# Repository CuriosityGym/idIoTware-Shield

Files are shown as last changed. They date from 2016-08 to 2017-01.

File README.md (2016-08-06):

# IdIoTware-Shield
##IoT with Arduino, Simplified

The idIoTware (pronounced “eye-dee-eye-oh-tee-ware”) Shield is a learning platform that offers both novices and advanced Arduino users, the opportunity to bring hundreds of projects alive quickly.

idIoTware provides an extremely flexible environment to express ideas and bring interactivity to simple projects, as well as providing for an easy way to implement, learn and prototype advanced projects and applications.

It is the “first of its kind” shield that offers this large variety of wireless communication options, input sensors, outputs and device extensibility. While offering high integration and compactness, the idIoTware Shield offers a large selection of latest hardware and features, accompanied by tested libraries, code and use cases. A must-have for the enthusiastic Arduino user.

##Product Images
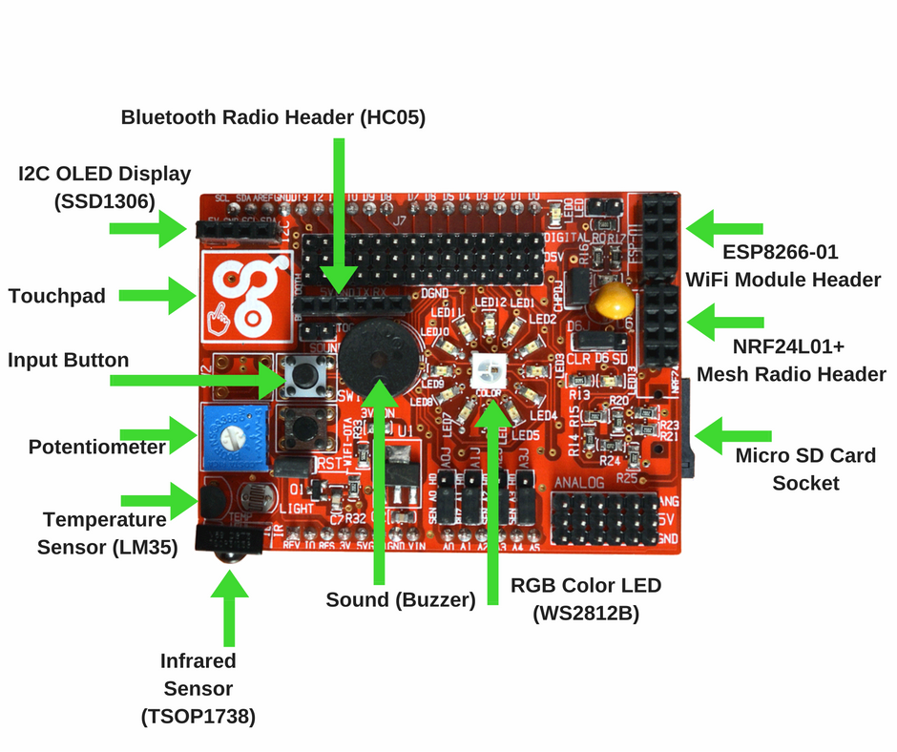
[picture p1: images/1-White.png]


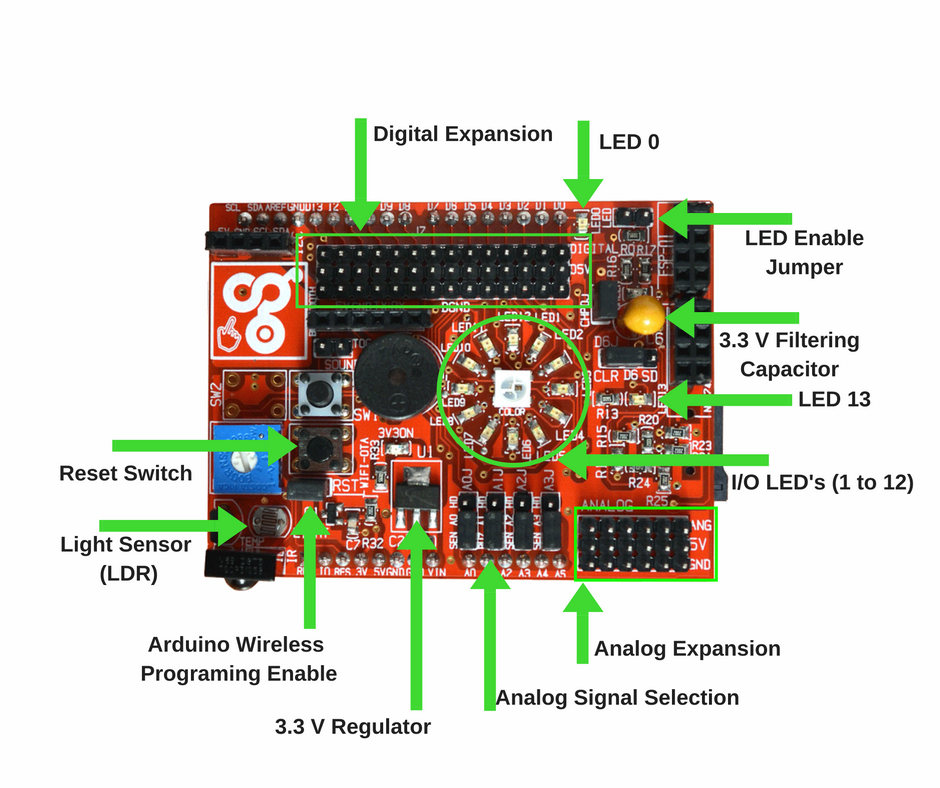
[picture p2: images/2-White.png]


##Hardware Specifications
#####Inputs

1. Integrated Temperature Sensor for measuring ambient temperature.
2. Integrated Light sensor that can measure relative light intensity.
3. Integrated Potentiometer to allow and simplify setting levels of intensity and thresholds.
4. Touch Pad and Input Switch to enable user inputs.
5. 38Khz Infrared Receiver which allows wireless remotes to control physical devices like robots.

#####Outputs

1. WS2812B Smart RGB LED for Colored Light Mixing.
2. I2C OLED Display for Visual Data Representation *
3. Multi tone Piezo buzzer for audio experiments.
4. Arduino Digital I/O’s connected to LED’s, enabling very quick debugging and error corrections.

#####Connectivity

1. ESP8226-01 Module to allow seamless Internet and Cloud Connectivity *
2. Connections and hardware that allows Arduino to be programmed over WiFi.
3. NRF24L01+ Module which allows for Mesh Networking and Collaborative Decision Making. *
4. Bluetooth and BLE Modules for connectivity to smartphones *

#####Extensibility/Advanced features

1. Expansion ports for Digital and Analog pins of Arduino.
2. Micro SD Card Socket for data accumulation and storage.*
3. Additional Voltage Regulator and onboard power conditioning hardware for 3.3 V devices.
4. Selection Hardware (Jumpers) for enable/disable features (User Selectable).
5. Compatible with Major Arduino Boards( new devices being added every week).

#####* Modules and SD Card to be purchased separately

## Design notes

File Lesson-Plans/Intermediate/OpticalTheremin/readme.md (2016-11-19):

#Optical Theremin
The theremin is a musical instrument that makes sounds as you wave your hand above it.

The light Dependent resistor or LDR is a light controlled variable resistor,
the resistance of a LDR decreases with increasing light intensity,
the resistance of LDR increases when the light intensity is decreasing,

However on the idIoTware shield, the LDR is wired such that with a higher Light intensity 
we get a higher Analog Voltage on Pin A3.

In this example we are going to use LDR sensor to make sounds.
When we wave our hand the light intensity falls on Light Dependent Resistor goes low .
This data is then captured by arduino through a voltage divider. 
We set the frequency according to the light value by using  map and tone functions in arduino to generate specific frequency .

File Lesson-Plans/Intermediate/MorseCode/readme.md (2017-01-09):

  **MORSE CODE**
    
    Morse code is a method of sending text messages by keying in a series of electronic pulses,
    usually represented as a short pulse (called a "dot") and a long pulse (a "dash"). The code 
    was devised by Samuel F. B. Morse in the 1840s
    
    In this example, we are using two NRF24L01 radio modules to transmit and receive Morse Code.
    On Transmitter side, Interpret presses on button (connected to digital pin 7) as Morse Code
    inputs and send it to receiver side using NRF24L01 radio.
    On Receiver side, NRF24L01 radio will receive the message and arduino will convert the signal 
    pattern consist of DOTs and DASHes to that particular letter and also print that letter to 
    OLED with its morse code.

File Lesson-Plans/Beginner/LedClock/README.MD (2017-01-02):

In this example 12 LEDs are used to show  time.  12 LEDs are connected in circualr pattern. All 12 LEDs represent number 1 to 12 of clock respectively. Depending upon the time, LED of that position will glow.If current time is 4:15 then 4th and 3rd LED will glow. 4th LED will indicate hour and 3rd LED will indicate minutes.LED which shows hours will glow conitinuously. LED which shows minutes will blink with delay of 1 sec. If time 6.30 then hour led and minute led will be the same (6th led) then 6th led will blink with delay of 250 miliseconds. e.g 4.20, 9.45, 11.55. We can set the current time in code.

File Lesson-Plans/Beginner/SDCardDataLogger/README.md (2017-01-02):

 SD card temperature logger
 This example shows how to log data from LM35 temperature sensor
 to an SD card using the SdFat library.
 In this example we have created a CSV file with the temperature values
 every one minute for 15 minutes. This interval rate and duration is configurable.
 If there is existing file, then it will create new file with different name.

 The circuit:
 LM35 sensor on analog pin A3
 
 SD card attached to SPI bus as follows:
 MOSI - pin 11
 MISO - pin 12
 CLK - pin 13
 CS - pin 4

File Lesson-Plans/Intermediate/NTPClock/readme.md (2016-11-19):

#NTP Clock

Most computers today use the NTP Clock to synchronise their internal clocks to an accurate atomic clock, 
which presents its time on the web.

#Working
In this example, we are going to display the Time, Date and Temperature readings on OLED display.
We need to setup the timezone first. 
By using idiotware.herokuapp.com, we are able to get the current zone  of the device, by using IP address. 
Once we get the timezone, we request timeapi.org to get the current time and date.
Once we get the data, we are ready to display it on OLED display.

Upload the code and you will be able to see the clock on the display with the current Time,date and temperature readings.

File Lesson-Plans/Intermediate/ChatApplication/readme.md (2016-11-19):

#Chat Application Using Idiotware Shield

What if, we could share data without wires or connecting to the Internet?

How cool would it be if you could communicate with people inside your home or work place
without a net pack or Internet Connection? 

A Private wireless Chat Room maybe?

What if we could customize our chat-screen with our own imaginations?

All this is possible with a arduino, idIoTware shield and the Wireless module nRF24L01. 

This Arduino Chat Room uses nRF24L01 to set up a low cost Chat Room in your local area.
You can extend the chat coverage by using nrf24l01 radio module with an external antenna.

#Working

In this example we are using NRF24L01 radio module and arduino to communicate to the other arduino and Nrf24L01 radio module using the serial monitor.

Here we are creating local mesh between two radio modules(Nrf24L01).

The two sets of  Arduino and nRF24L01 are connected together to establish a wireless  communication link so that they could talk to each other.

The nRF24L01 are half duplex transceiver modules, hence they can send and receive data.

The data is sent from the user using arduino Serial monitor , by typing on his keyboard,and this data can be received and displayed on the receivers  oled display,  which  is on the idiotware shield, and vice- a versa.

This project is limited to just adding two members to the Chat room, But the nRF24L01 has capability to handle 6 connections,  and so there could be a maximum of 6 members in our chat room, each talking or chatting with each other.

This chat room coverage could be upto 100 meters depending upon the nRF24L01 Modules range.

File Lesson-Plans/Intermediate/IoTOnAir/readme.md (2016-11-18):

**IOT OnAir**
-------------

This is a device that could be used to notify any specific content on google calendar with idIoTware Shield.

The event from the Google calendar notifies the Maker channel on the IFTTT server. 
Once the maker channel is triggered, it will then send a ‘Get request’ to the blynk server.

For example: http://blynk-cloud.com/yourAPIkey/update/V0?value=250?pin=V0&value=0&pin=V0&value=0

Note: here "value" is the whole number that is used to set intensity of red color on idIoTware shield from 0 to 255.

So what is IFTTT?
-----------------

IFTTT is a free web-based service that allows users to create chains of simple conditional statements, called "recipes", which are triggered based on changes to other web services such as Gmail, Facebook, Instagram, Twitter and many more.

IFTTT is an abbreviation of "If This Then That".

User can use the maker channel to connect there hardware with other services and trigger them according to the recipes.

For example: The event from the google calendar notifies the maker channel on the IFTTT server.
Once the maker channel is triggered, it will then send a ‘Get request’ to the blynk server.

Configuring IFTTT and Blynk APP
-------------------------------

1. Go to www.ifttt.com

2. Sign in the account

3. Create new applet

4. Select Google Calendar.

5. For this example we choose event from search starts. NOTE:You can choose any of the three.

6. Write the keyword you want to trigger from Google Calendar.

7. Add Maker channel

8. Select Make a web request

9. You will need to add url for blynk server and change content type to text/plain
10. Create new project and email the token key

In your Arduino program, you need to copy the Token key generated in the blynk app and also need to write your ssid and password for wifi . You are now ready to upload the code. You will see your ON Air light up when the google calendar event is called.

1. Configuring Arduino IDE and idIoTware shield

2. Connect One jumper to CHPD for enabling esp8266

3. Connect One jumper to CLR means color that is RGB LED and D6.

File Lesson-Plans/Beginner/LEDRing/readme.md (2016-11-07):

#idIoTware Shield LED Ring Demo

This Arduino program demonstrates the ring of LED's on the shield to light up one after the other.

###Hackster Project
https://www.hackster.io/30115/led-ring-patterns-7f5cd2?ref=channel&ref_id=29476_trending___&offset=1

###Video

https://www.youtube.com/watch?v=BFscHxyjzhA

#Hardware Required
1. idIoTware Shield
2. Arduino Uno.
3. USB cable to connect arduino  to computer
4. One jumper to enable the LED Ring

The following patterns defined in the sketch.

a. Sweep

b. Half Circle

c. A Curtain

d. Fast and Slow Pattern.

The LED’s on the ring are connected from Digital Pin 1 to Digital pin 12 of the Arduino.

We need to initialize this LED's in void setup() function of arduino sketch, to be outputs.

The void loop() runs over and over again, repeatedly till power is removed. Out LED patterns are executed within the loop().

We will use the function for example the sweep(1).The “1” means how many repetitions you wish to do for that animation.This value can only be whole numbers, and not with decimal points. 

In a similar manner, you can also use the other functions to mix and match animations on the LED Ring.

Additionally,you can use touch pad or potentiometer as the input to control the 12 led’s.

You can now make your own program and create patterns on the LED’s and put this up on your Christmas tree
or any other decorations to bring that interactive look to your project.

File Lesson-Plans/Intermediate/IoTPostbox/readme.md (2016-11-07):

#IoT PostBox
    
In this project, I am going to demonstrate how to build your own IoT aware Postbox with the help of the idIoTware shield in a few easy steps. This postbox alerts you about new envelopes dropped inside a postbox by the mailman. 

### Hackster Project
https://www.hackster.io/30290/smart-iot-postbox-3287f8?ref=user&ref_id=11008&offset=1

### Video 

https://www.youtube.com/watch?v=VOWjkQzXQHM

You will need the following things to get started. 
An Arduino UNO
idIoTware shield. 
USB cable to connect arduino  to computer.
Esp 8266 - 01, programmed with ESP-link firmware
One jumper to enable the Chpd pin.
One Postbox
External 9v 1A Power adapter.   

The LDR ( Light Dependent Resistor)  on IdIoTWare shield is used as sensor to detect a letter being dropped into the letterbox. The on board WS2812 Led (addressable RGB LED) on IdIoTWare shield is continuously ON (WHITE Color) which acts as a light source, and reflects light onto the LDR. As soon as a letter is dropped into the postbox, there is an interruption in light -  the light intensity on LDR changes due to reflection. The Arduino continuously monitors the change in the value of the LDR and when it notices a change in value, it sends an email.  Here we are using IFTTT to send a pre configured email. 

###So what is IFTTT?
Introduction Video to IFTTT https://www.youtube.com/watch?v=CEAVFU3ELcI

IFTTT is an abbreviation of "If This Then That"

IFTTT is a free web-based service that allows users to create chains of simple conditional statements, called "recipes", which are triggered based on changes to other web services such as Gmail, Facebook, Instagram, and many more.

You need to  create an account on IFTTT and create your recipe.

You need to make the IFTTT account. click on the link below https://ifttt.com/join and sign up the account.

We are using Maker and Gmail channel to trigger an event.
If there is new letter in postbox, Arduino will send POST request to Maker channel.
if Maker then Gmail’
If Maker Event "New Letter",
then send an email from "abcd@gmail.com".

Connect the esp8266 01 module to ESP-01 header on the top right, such that the antenna is facing outside. ( See Image) We need to Connect jumper to the chpd pin header for the esp to work correctly. 

Once we upload the code in arduino, place the Arduino with double sided sticky tape inside the postbox. Make sure the whole bottom of the arduino board is insulated from the metal areas of the postbox. Post the letter in the box, and you will see the message” new Letter!! “ in serial monitor and when you check your mail you will find IFTTT message saying you got a letter!!

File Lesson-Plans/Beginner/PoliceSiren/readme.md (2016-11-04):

# Police Siren with the idIoTware Shield

### Hackster project
https://www.hackster.io/30210/police-siren-bf8169?ref=channel&ref_id=29476_trending___&offset=0

### Video
https://youtu.be/00wCUanNaoU

### Project Description

In this project, I am going to demonstrate how to make your own police siren alarm with the help of the idIoTware shield.

You will need following things to get started. 
An Arduino Uno.
An idIoTware shield. 
A USB cable to connect Arduino to Computer.
A 2 pin Jumper to connect the Buzzer to the Arduino A1 pin.
A jumper that connects CLR to D6 for Color LED.

The buzzer is already connected on the shield, but it has to be enabled using the 3 pin  Selection Jumper SEL 1.

We need to Connect the “BUZ” pin to the center pin on SEL1 3 pin header, effectively connecting the Buzzer to the A1 pin.

In method police_siren() the tone for the siren is mentioned.Use this function in the loop to run the siren over and over again.

For more reference on tone function please visit the link in the description.  

Once we upload the code in arduino, we are going to hear the police siren, along with the RGB Color LED showing a Red and Blue blinking light.

You can now make your own program that play siren when someone unauthorized comes at your house.This will alert the neighbours about activity inside your home.  

You can also use the buzzer to alert you when the temperature increases beyond a certain limit, as measured by the integrated temperature sensor on the idIoTware shield. We will learn how to measure temperature in a later video. 

Another use for the buzzer is to generate any set of tones like nursery rhymes or the happy birthday song.

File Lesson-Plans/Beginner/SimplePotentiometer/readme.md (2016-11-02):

  A potentiometer, or "pot" for short, is a control knob.
  It's the same type of control you'd use to change volume,
  dim a lamp, etc. A potentiometer changes resistance as it
  is turned. By using it as a "voltage divider", the Arduino
  can sense the position of the knob, and use that value to
  control whatever you wish.

  In this example we are going to Turn ON and OFF sequence of 12 LEDs
  depending upon the position of the knob of potentiometer.
  As we turn potentiometer from initial position to final position,
  12 LEDs will glow one by one depending to value of potentiometer.
  If we turn knob in reverse direction then LEDs will turn OFF one by
  one depending upon the value of potentiometer

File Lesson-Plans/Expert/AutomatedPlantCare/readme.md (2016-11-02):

#**idIoTWare Shield Hydroponics**
#####**Attention: Please install all libraries from our Github Repository to enable this example to run.**

In this example we are using ESP8266-01 Wifi Module with esp-link firmware, Soil moisture sensor to sense moisture in soil, walter level sensor to detect water level and motor to water the plant. If plant's soil is dry then moisture sensor will give HIGH input to arduino then arduino turns ON the motor. We have used mosfet to turn ON and turn OFF the motor. Arduino logs the data on thingspeak and sends mail to the user.                                                    

ThingSpeak is an open source Internet of Things (IoT) application and API to store and retrieve data from things using the HTTP protocol over the Internet or via a Local Area Network. ThingSpeak enables the creation of sensor logging applications, location tracking applications, and a social network of things with status updates. To log the data to thingspeak, you need to create thingspeak account and then create channel and use that channel's API Key in this code.                

Here we are using IFTTT to trigger an event.                                                                             
IFTTT is a free web-based service that allows users to create chains of simple conditional statements,
called "recipes", which are triggered based on changes to other web services such as Gmail, Facebook,
Instagram, and many more.IFTTT is an abbreviation of "If This Then That"
Create account on IFTTT and create your recipe.

We are using Maker and Gmail channel to trigger an event.

If plant is watered, Arduino will send POST request to maker channel.  
if Maker then Gmail
If Maker Event "Plant_watered", then send an email from "abcd@gmail.com"  

#####**Setup:**
1.create account on thingspeak and channel                                         
2.create account on IFTTT, connect to maker channel and make recipe.                                                    
3.replace API key for thingspek channel and maker channel                                                     
4.install all libraries from our Github Repository to enable this example to run.                                         
5.connect sensors to proper input pins and caliberate the sensors for perfect reading.

#####**Precautions:**
1.Use mosfet or relay module to drive motor.                                                                             
2.keep sensor properly in soil to get proper readings

#####**Images:**  put link here

#####**Video:**  put link here

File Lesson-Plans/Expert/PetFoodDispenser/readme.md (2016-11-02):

# **idIoTWare Shield Dog Food Feeder**
#####  **Attention: Please install all libraries from our Github Repository to enable this example to run.**
    
In this example we are using ESP8266-01 Wifi Module  and a Servo motor to dispense food from 3d printed food jar.

Blynk is a platform with iOS and Android apps to control Arduino, Raspberry Pi and the likes over the Internet. 
You can easily build graphic interfaces for all your projects by simply dragging and dropping widgets.

Downloads, docs, tutorials: http://www.blynk.cc
  Blynk community:            http://community.blynk.cc 

To send data from Blynk to arduino or get data from arduino to blynk app you need to install Blynk app on your 
smartphone, create account to log in to the app then you will get a unique token number then use that token number in 
this code to create your own project.

In this example we have used ESP8266_Lib.h and BlynkSimpleShieldEsp8266.h  library to make communication between arduino
and Blynk app.We have used Servo.h library to control servo motor. In this code we have used vitual pin(v1) to receive data 
from blynk app. oN Blynk app we have added a button icon to send ON and OFF signal to arduino. If you press button then servo
will rotate 60 degree in clockwise direction and food will get dispensed for 5 seconds and after thet servo will come back to 
initial positon. You can change rotation angle of servo and time for which you want to dispense food. 

#####**Setup:**

1.install all libraries from our Github Repository to enable this example to run.                                 
2.create account on BLYNK and use your Auth Token number in code.                               

#####**Precautions:**

1.Enter correct Auth Token number.                                                                                 
2.Virtual pin number in code and BLYNK app must be same.                                                                 

#####**Images:** put link here
#####**Video:** put link here

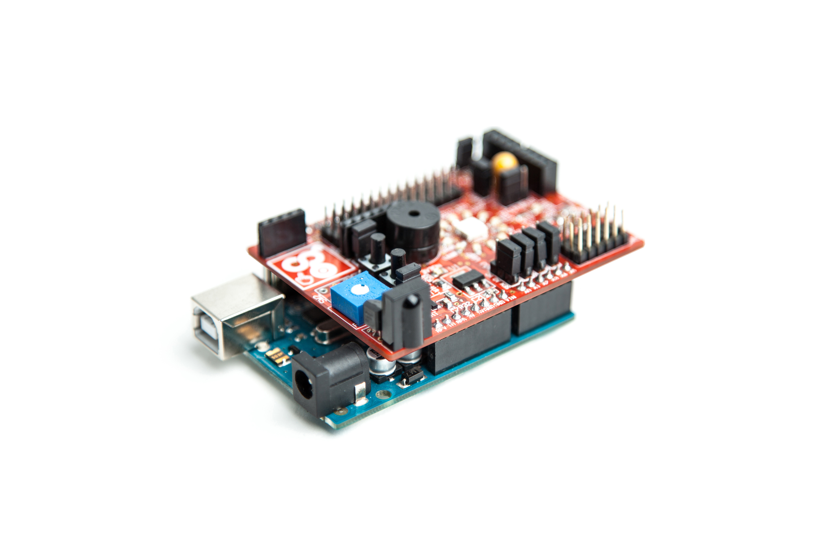
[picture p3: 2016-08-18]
images/idIoTware Shield On Arduino Perspective.jpg

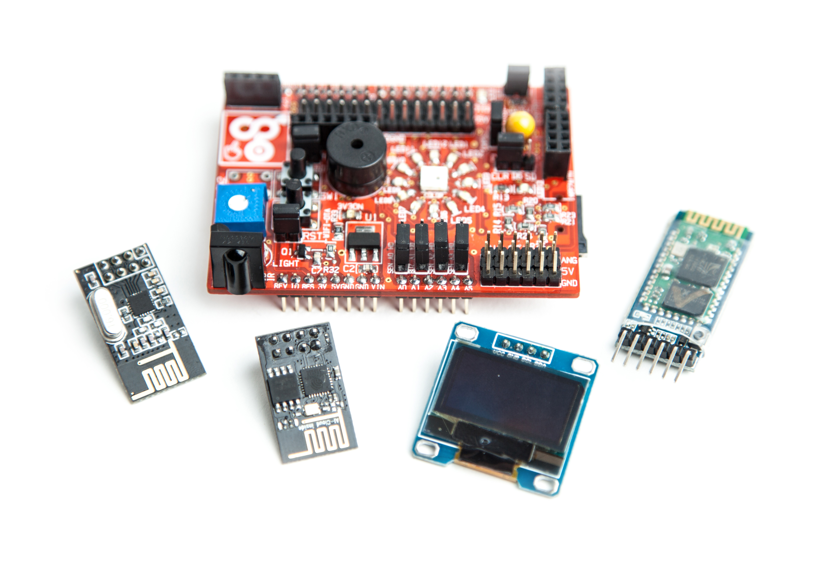
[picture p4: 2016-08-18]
images/idIoTware Shield with Modules.JPG

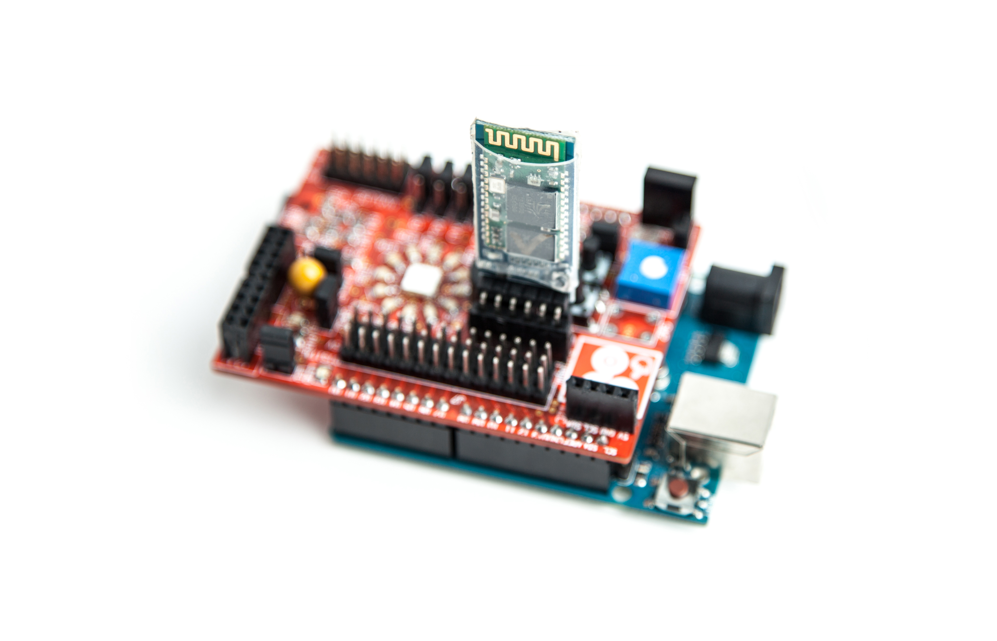
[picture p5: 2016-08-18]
images/idIoTware Shield On Arduino with Bluetooth.JPG

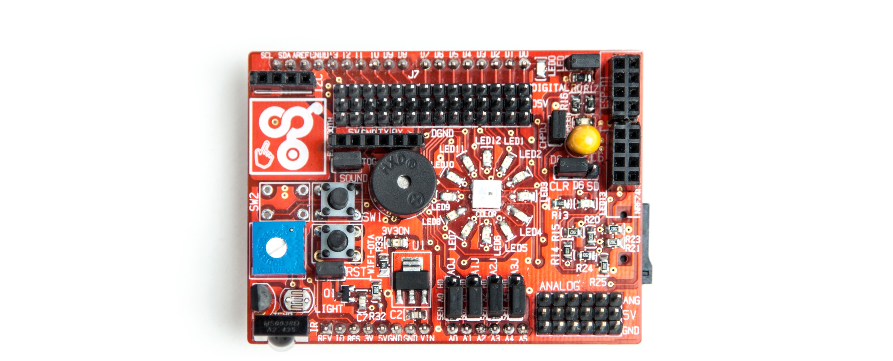
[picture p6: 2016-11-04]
images/idIoTware Shield Top View.JPG

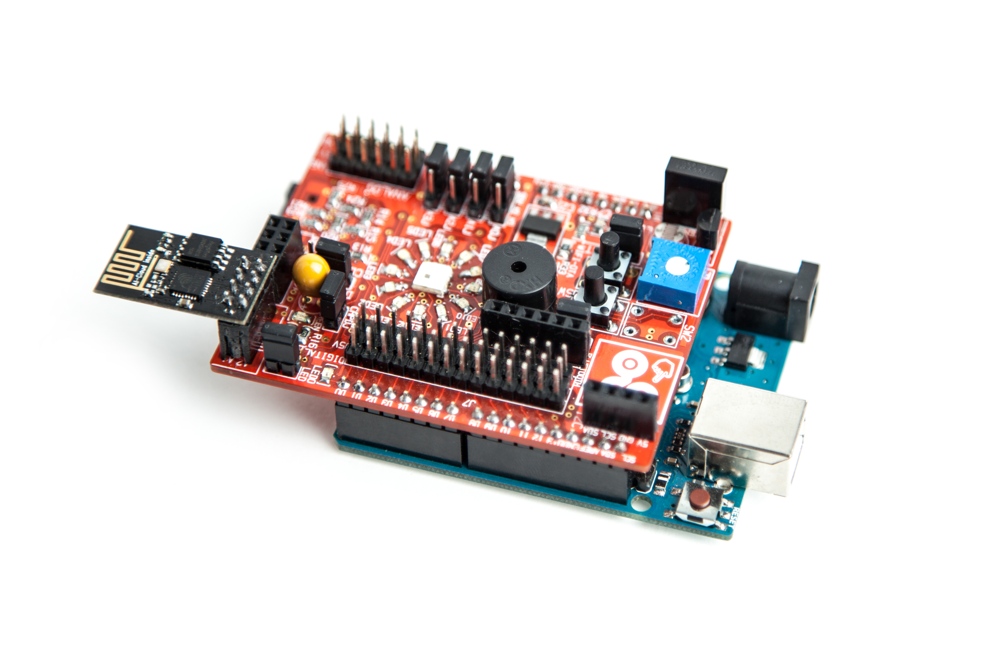
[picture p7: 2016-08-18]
images/idIoTware Shield On Arduino with ESP-01.JPG

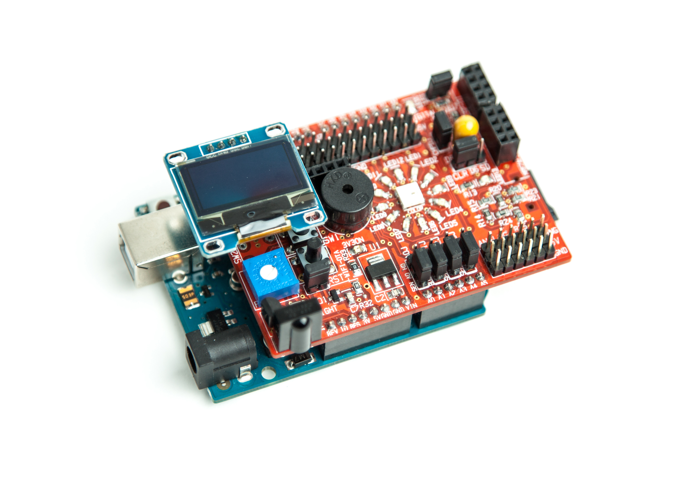
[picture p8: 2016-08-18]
images/idIoTware Shield On Arduino with OLED.JPG

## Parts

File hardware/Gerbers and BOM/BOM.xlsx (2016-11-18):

Part | Value | Device | Package | Description
PCB |  | PCB | 74mm by 56 mm | PCB Material :(Rigid)FR－4 PCB Size: (74 mm ) × (56 mm ) PCB Layer: 2 Thickness: 1.6mm Copper Weight: 1oz PCB Colour: Red Silkscreen:White Pads Finished: HASL lead free Via solder mask :solder mask cover Minimum trace/space: 8mil Minimum hole size: 13 mil
0 |  | LEDCHIPLED_0805 | CHIPLED_0805 | RED LED
1 |  | LEDCHIPLED_0805 | CHIPLED_0805 | RED LED
2 |  | LEDCHIPLED_0805 | CHIPLED_0805 | RED LED
3 |  | LEDCHIPLED_0805 | CHIPLED_0805 | RED LED
3.3V_REG |  | V_REG_LM1117SOT223 | SOT223 | Voltage Regulator LM1117 VREG-08170 RegulatorLM1117VREG-08170
3.3V ON |  | M02PTH | 1X02 | Standard2-pin0.1"header.
4 |  | LEDCHIPLED_0805 | CHIPLED_0805 | RED LED
5 |  | LEDCHIPLED_0805 | CHIPLED_0805 | RED LED
5V |  | M06SILK_FEMALE_PTH | 1X06 | Header6CONN-08437
6 |  | LEDCHIPLED_0805 | CHIPLED_0805 | RED LED
7 |  | LEDCHIPLED_0805 | CHIPLED_0805 | RED LED
8 |  | LEDCHIPLED_0805 | CHIPLED_0805 | RED LED
9 |  | LEDCHIPLED_0805 | CHIPLED_0805 | RED LED
10 |  | LEDCHIPLED_0805 | CHIPLED_0805 | RED LED
11 |  | LEDCHIPLED_0805 | CHIPLED_0805 | RED LED
12 |  | LEDCHIPLED_0805 | CHIPLED_0805 | RED LED
13 |  | LEDCHIPLED_0805 | CHIPLED_0805 | RED LED
SEL0 |  | JP2E | JP2 | JUMPER
SEL1 |  | JP2E | JP2 | JUMPER
SEL2 |  | JP2E | JP2 | JUMPER
SEL3 |  | JP2E | JP2 | JUMPER
SIG |  | M06SILK_FEMALE_PTH | 1X06 | Header6CONN-08437
Bluetooth |  | M06SILK_FEMALE_PTH | 1X06 | Header6CONN-08437
C1 | 104 |  | CAP0805 | 805Capacitor
C2 | 104 |  | CAP0805 | 805Capacitor
C3 | 104 |  | CAP0805 | 805Capacitor
C4 | 106 |  | CAP0805 | 805Capacitor
C5 | 30pF |  | CAP0805 | 805Capacitor
C6 | 100u/16V |  | Electrolytic | Electrolytic
C7 | 0.1u |  | CAP0805 | 805Capacitor
CHPD |  | M02PTH | 1X02 | Standard2-pin0.1"header.Use
COLOR |  | WS2812B_5050N | WS2812B_5050N | WS2812B-NARROW
5V |  | M14 | 1X14 | Header14
D6J |  | JP2E | JP2 | JUMPER
GND |  | M14 | 1X14 | Header14
SIG |  | M14 | 1X14 | Header14
ESP-01 |  | WIRELESS-WIFI-ESP-01 | 02x04 | 02x042rowby4
GND |  | M06SILK_FEMALE_PTH | 1X06 | Header6CONN-08437
I2C |  | M04PTH | 1X04 | Header4CONN-09696
IR |  | TSOP1738 | TSOP1738 | Vishay TSOP1738
LED_EN |  | M02PTH | 1X02 | Standard2-pin0.1"header.Use
LIGHT |  | PHOTOCELLPTH | PHOTOCELLPTH | PHOTOCELLCdSphotoresistor
WIFI |  | GREEN | LEDCHIPLED_0805 | Green LED
SD |  | MICROSD | MICROSD | MICROSD
NRF24L01 |  | WIRELESS-NRF24L01 | 02x04 | 02x04
POT |  | 3386-P | 3386P | 3386Series
Q1 |  | BC847 | BC847 | SOT23NPNTRANSISTOR
R0 | 1200 |  | R-US_M0805 | M0805RESISTORAmericansymbol
R1 | 1200 |  | R-US_M0805 | M0805RESISTORAmericansymbol
R2 | 1200 |  | R-US_M0805 | M0805RESISTORAmericansymbol
R3 | 1200 |  | R-US_M0805 | M0805RESISTORAmericansymbol
R4 | 1200 |  | R-US_M0805 | M0805RESISTORAmericansymbol
R5 | 1200 |  | R-US_M0805 | M0805RESISTORAmericansymbol
R6 | 1200 |  | R-US_M0805 | M0805RESISTORAmericansymbol
R7 | 1200 |  | R-US_M0805 | M0805RESISTORAmericansymbol
R8 | 1200 |  | R-US_M0805 | M0805RESISTORAmericansymbol
R9 | 1200 |  | R-US_M0805 | M0805RESISTORAmericansymbol
R10 | 1200 |  | R-US_M0805 | M0805RESISTORAmericansymbol
R11 | 1200 |  | R-US_M0805 | M0805RESISTORAmericansymbol
R12 | 1200 |  | R-US_M0805 | M0805RESISTORAmericansymbol
R13 | 1200 |  | R-US_M0805 | M0805RESISTORAmericansymbol
R14 | 100 |  | R-US_M0805 | M0805RESISTORAmericansymbol
R15 | 200 |  | R-US_M0805 | M0805RESISTORAmericansymbol
R16 | 560 |  | R-US_M0805 | M0805RESISTORAmericansymbol
R17 | 10k |  | R-US_M0805 | M0805RESISTORAmericansymbol
R18 | 10k |  | R-US_M0805 | M0805RESISTORAmericansymbol
R19 | 20k |  | R-US_M0805 | M0805RESISTORAmericansymbol
R20 | 10k |  | R-US_M0805 | M0805RESISTORAmericansymbol
R21 | 20k |  | R-US_M0805 | M0805RESISTORAmericansymbol
R22 | 10k |  | R-US_M0805 | M0805RESISTORAmericansymbol
R23 | 20k |  | R-US_M0805 | M0805RESISTORAmericansymbol
R24 | 10k |  | R-US_M0805 | M0805RESISTORAmericansymbol
R25 | 20k |  | R-US_M0805 | M0805RESISTORAmericansymbol
R26 | 100k |  | R-US_M0805 | M0805RESISTORAmericansymbol
R27 | 100k |  | R-US_M0805 | M0805RESISTORAmericansymbol
R28 | 10k |  | R-US_M0805 | M0805RESISTORAmericansymbol
R29 | 10k |  | R-US_M0805 | M0805RESISTORAmericansymbol
R30 | 330 |  | R-US_M0805 | M0805RESISTORAmericansymbol
R31 | 10k |  | R-US_M0805 | M0805RESISTORAmericansymbol
R32 | 20k |  | R-US_M0805 | M0805RESISTORAmericansymbol
RST |  | SPST_TACT-EVQQ2 | SPST_TACT-EVQQ2 | EVQ-Q2SMT6mmswitch | Should have a small Top
SOUND |  | F/CM12P | F/CM12P | F/CM12PBuzzer
INPUT |  | SPST_TACT-EVQQ2 | SPST_TACT-EVQQ2 | EVQ-Q2SMT6mmswitch
TEMP |  | LM35 | LM35 | TO92
TOG |  | M02PTH | 1X02 | Standard2-pin0.1"header.Use
TTP-223-BA6 |  | TTP-223 | TTP-223 | SOT23-6
WIFI-OTA |  | M02PTH | 1X02 | Standard2-pin0.1"header.Use

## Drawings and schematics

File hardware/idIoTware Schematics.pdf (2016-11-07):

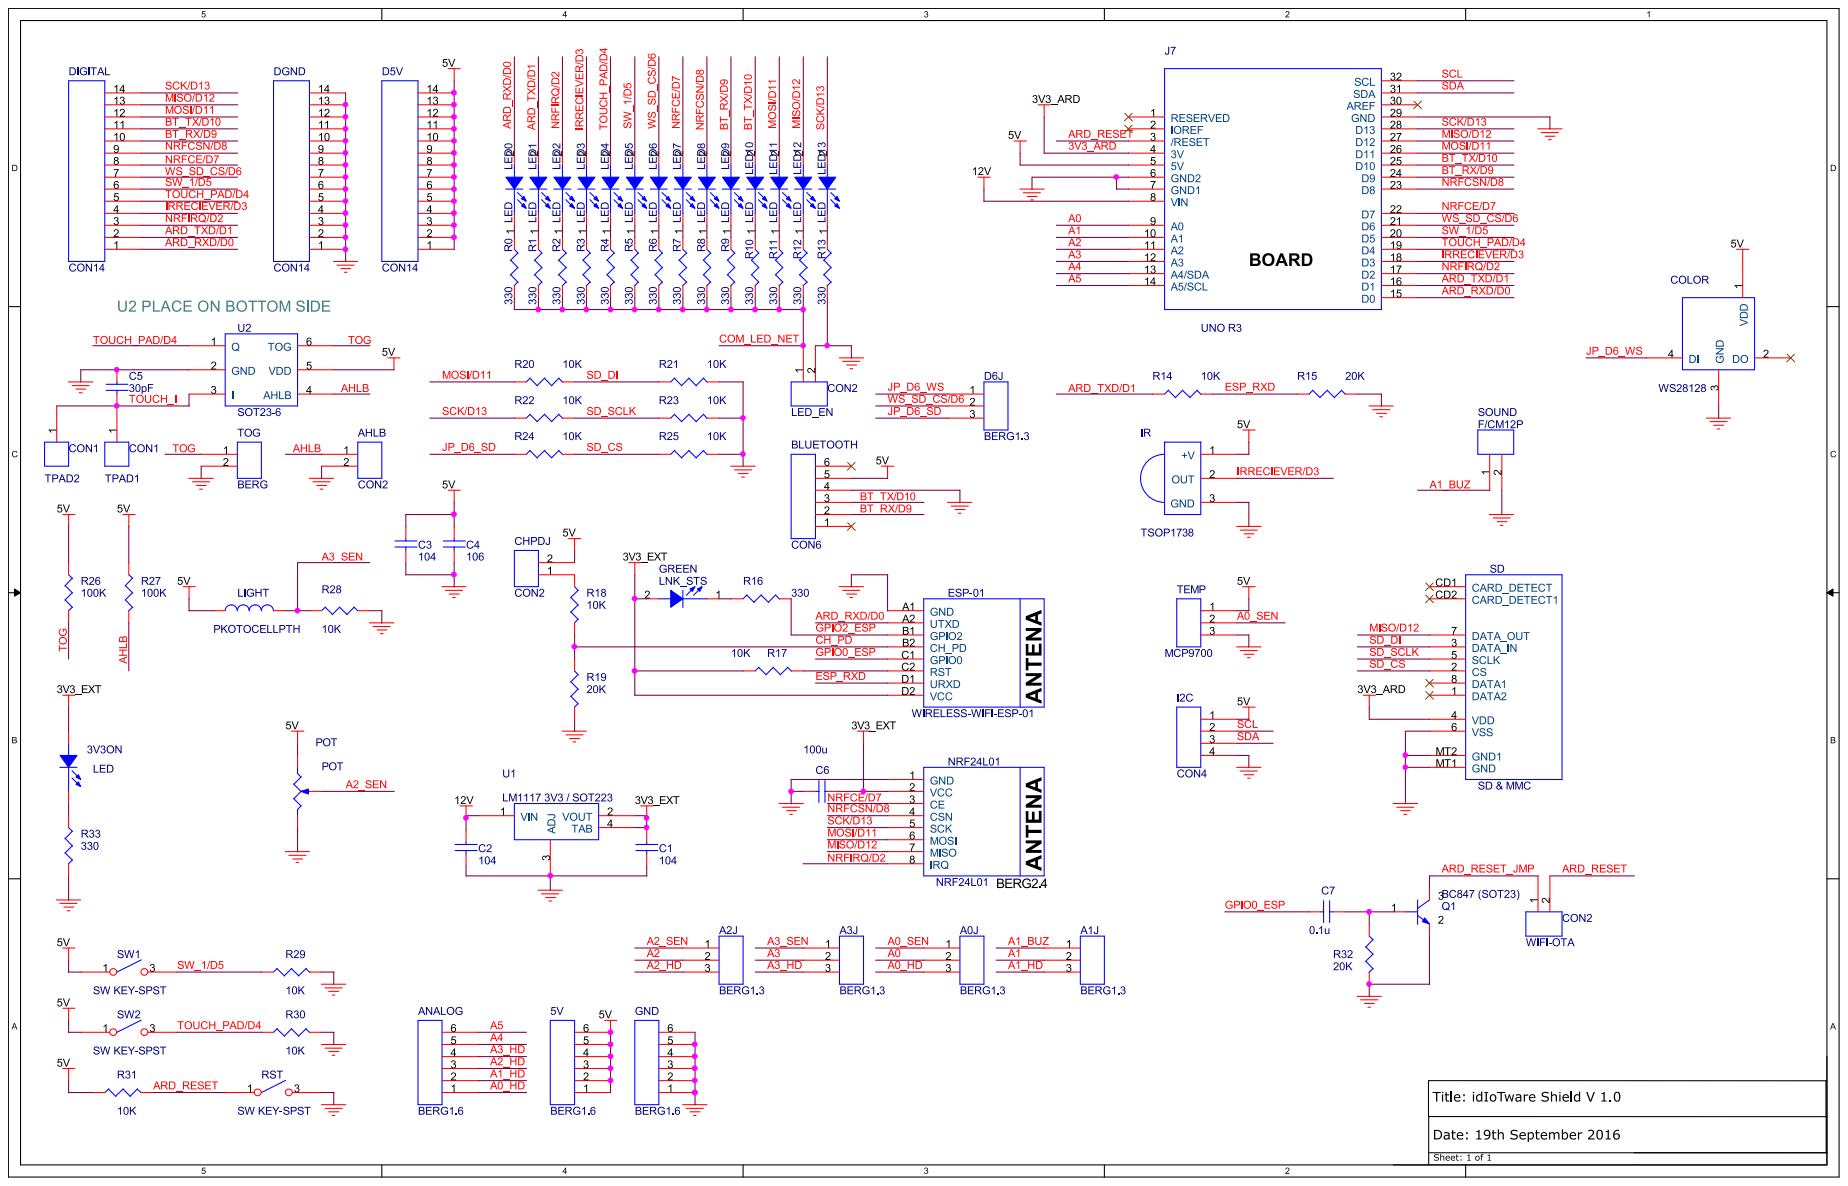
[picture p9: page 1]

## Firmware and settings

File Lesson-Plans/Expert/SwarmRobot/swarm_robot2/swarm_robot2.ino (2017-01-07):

#include <RF24Network.h>
#include <RF24.h>
#include <SPI.h>
#include "U8glib.h"

// Hardware configuration
// Set up nRF24L01 radio on SPI bus plus pins 9 & 10

RF24 radio(7,8);

// Network uses that radio
RF24Network network(radio);

// Address of our node
const uint16_t this_node = 0;

// Address of the other node
const uint16_t other_node = 1;

boolean send_message = false;
char messageToSend[32] = "";  //
 //char messageToRecieve[32] = "";
int melody[]= {2000,2000,2000,2000};
// note durations: 4 = quarter note, 8 = eighth note, etc.:
int noteDurations[] = { 8,8,8,8 };

U8GLIB_SH1106_128X64 u8g(U8G_I2C_OPT_NONE);	// I2C / TWI 

String inputString = "";         // a string to hold incoming data
boolean stringComplete = false;  // whether the string is complete

int motor_left[] = {2, 4};
int motor_right[] = {A0, A1};
int motor1Speed = 3;
int motor2Speed = 5;
#define trigPin 9
#define echoPin 6
byte potPin = A2;
int speed;
long previousMillis = 0;        // will store last time LED was updated
long interval = 1000;           // interval at which to blink (milliseconds)
int duration, distance;
int x, y;
boolean msg=false;
// --------------------------------------------------------------------------- Setup
void setup() 
     { 
       Serial.begin(57600);
       pinMode(trigPin, OUTPUT);
       pinMode(echoPin, INPUT);
       //pinMode(potPin, INPUT);
       pinMode(motor1Speed , OUTPUT);
       pinMode(motor2Speed , OUTPUT);
       // Setup motors
       for(byte i = 0; i < 2; i++)
          {
            pinMode(motor_left[i], OUTPUT);
            pinMode(motor_right[i], OUTPUT);
          }
       u8g.setFont(u8g_font_unifont);
       u8g.firstPage();  
       do 
        {
          u8g.setPrintPos(0, 10); 
         u8g.print("Robot " );
         u8g.setPrintPos(45, 10); 
         u8g.print(this_node);
        } while( u8g.nextPage() ); 
 
       SPI.begin();
       radio.begin();
       network.begin(/*channel*/ 90, /*node address*/ this_node);
         
      }


// --------------------------------------------------------------------------- Loop
void loop() 
    {  
      // Pump the network regularly
       network.update();
       speed = analogRead(A2);
     //  Serial.println(speed);
       unsigned long currentMillis = millis();
       
       if(currentMillis - previousMillis > interval)
         {
           // save the last time you blinked the LED 
           previousMillis = currentMillis;   
           digitalWrite(trigPin, HIGH);
           digitalWrite(trigPin, LOW);
           duration = pulseIn(echoPin, HIGH);
           distance = (duration/2) / 29.1;
           x = (x + distance)%100;
           y = (x + y + distance)%100;
           Serial.println(distance);
           
         } 
      if (distance <= 6)
          { 
            motor_stop();
          }  
         
      if (send_message )
          { 
          
           
          //  inputString = String(x) + "   " + String(y);
            RF24NetworkHeader header1( other_node);
            boolean message = network.write(header1, inputString.c_str(), 32); // send message to other user
            if (message)
               {
                 Serial.print("Robot2: ");  // print message on serial monitor
                 Serial.println(inputString);
                 send_message = false;
               }
          
            else
               {
                 Serial.println("could not write....\n");  // if it is failed to send message prompt error
              
                // stringComplete=false;
                // inputString="";
               }
          }    
    
     
      // else
      //    {
            
           
             // Is there anything ready for us?
            while (network.available() )   
                  { 
                    // If so, grab it and print it out
                    RF24NetworkHeader header;
                    char messageToRecieve[32] = "";
                    boolean recieve = false;
                    while (!recieve)
                          {
                            recieve = network.read(header, messageToRecieve , 32 );
                            Serial.print("Robot1: ");   // print recived data on okserial monitor
                            Serial.println(messageToRecieve);
                            for(int thisNote = 0; thisNote < 4; thisNote++) 
                               {
                                // to calculate the note duration, take one second divided by the note type.
                                //e.g. quarter note = 1000 / 4, eighth note = 1000/8, etc.
                                int noteDuration = 1000/noteDurations[thisNote];
                                tone(A1, melody[thisNote],noteDuration);
                                // to distinguish the notes, set a minimum time between them.
                                // the note's duration + 30% seems to work well:
                                int pauseBetweenNotes = noteDuration * 1.60;
                                delay(pauseBetweenNotes);
                                // stop the tone playing:
                                noTone(8);
                               }
                               
                             u8g.firstPage();  
                             do 
                               {
                                 u8g.drawStr(0,10, "Robot2 says: "); 
                                 u8g.drawStr(0,25, "found obstacle: ");
                                 u8g.setPrintPos(0, 44); 
                                 u8g.print(messageToRecieve); 
                               } while( u8g.nextPage() );  
                               moveRobot(messageToRecieve);
                
                              
                         }
                 }
          }
   // }     
void moveRobot(String action)
    {
      
      if(action == "RIGHT")
        {
           Serial.println("RIGHT message Recived");
           inputString = "ACKR";
           send_message = true; 
            motor_stop();
           delay(250);
           turn_right();
           delay(800);
           motor_stop();
           delay(250);
        }
        if(action == "FORWARD")
        {
           
             Serial.println("FORWARD message Recived");
            // inputString = "ACKF";
            // send_message = true; 
             drive_forward();
        }
        if(action == "GO")
        {
           
             Serial.println("GO message Recived");
             inputString = "GO";
             send_message = true; 
             drive_forward();
        }
         if(action == "STOP")
        {
           
             Serial.println("STOP message Recived");
            // inputString = "ACKF";
            // send_message = true; 
             motor_stop();
        }
    }

// --------------------------------------------------------------------------- Drive

void motor_stop()
     {
       digitalWrite(motor_left[0], LOW);
       digitalWrite(motor_left[1], LOW);

       digitalWrite(motor_right[0], LOW);
       digitalWrite(motor_right[1], LOW);
       delay(25);
     }


void drive_forward()
     { 
       analogWrite(motor1Speed, speed/4);  
       analogWrite(motor2Speed, speed/4); 
       digitalWrite(motor_left[0], HIGH);
       digitalWrite(motor_left[1], LOW);

       digitalWrite(motor_right[0], HIGH);
       digitalWrite(motor_right[1], LOW);
     }

void turn_right()
     { 
       analogWrite(motor1Speed, speed/4);  
       analogWrite(motor2Speed, speed/4); 
       digitalWrite(motor_left[0], HIGH);
       digitalWrite(motor_left[1], LOW);

       digitalWrite(motor_right[0], LOW);
       digitalWrite(motor_right[1], HIGH);
     }
 

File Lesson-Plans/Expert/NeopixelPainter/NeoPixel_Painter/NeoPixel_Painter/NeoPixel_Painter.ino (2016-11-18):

// ADAFRUIT NEOPIXEL LIGHT PAINTER SKETCH: Reads 24-bit BMP image from
// SD card, plays back on NeoPixel strip for long-exposure photography.

// Requires SdFat library for Arduino:
// http://code.google.com/p/sdfatlib/

// As written, uses a momentary pushbutton connected between pin A1 and
// GND to trigger playback.  An analog potentiometer connected to A0 sets
// the brightness at startup and the playback speed each time the trigger
// is tapped.  BRIGHTNESS IS SET ONLY AT STARTUP; can't adjust this in
// realtime, not fast enough.  To change brightness, set dial and tap reset.
// Then set dial for playback speed.

// This is a 'plain vanilla' example with no UI or anything -- it always
// reads a fixed set of files at startup (frame000.bmp - frameNNN.bmp in
// root folder), outputs frameNNN.tmp for each (warning: doesn't ask, just
// overwrites), then plays back from the file(s) each time button is tapped
// (repeating in loop if held).  More advanced applications could add a UI
// (e.g. 16x2 LCD shield), but THAT IS NOT IMPLEMENTED HERE, you will need
// to get clever and rip up some of this code for such.

// This is well-tailored to the Arduino Uno or similar boards.  It may work
// with the Arduino Leonardo *IF* your SD shield or breakout board uses the
// 6-pin ICSP header for SPI rather than pins 11-13.  This WILL NOT WORK
// with 'soft' SPI on the Arduino Mega (too slow).  Also, even with 'hard'
// SPI, this DOES NOT RUN ANY FASTER on the Mega -- a common misconception.

// Adafruit invests time and resources providing this open source code,
// please support Adafruit and open-source hardware by purchasing
// products from Adafruit!

// Written by Phil Burgess / Paint Your Dragon for Adafruit Industries.
// BSD license, all text above must be included in any redistribution.
#include <SPI.h>
#include <SD.h>
#include <avr/pgmspace.h>
#include "./gamma.h"

// CONFIGURABLE STUFF --------------------------------------------------------

#define N_LEDS       144 // Max value is 170 (fits one SD card block)
#define CARD_SELECT   10 // SD card select pin (some shields use #4, not 10)
#define LED_PIN        8 // NeoPixels connect here
#define SPEED         A2 // Speed-setting dial
#define BRIGHTNESS    A2 // Brightness-setting dial
#define TRIGGER       5 // Playback trigger pin
#define CURRENT_MAX 3500 // Max current from power supply (mA)

// The software does its best to limit the LED brightness to a level that's
// manageable by the power supply.  144 NeoPixels at full brightness can
// draw about 10 Amps(!), while the UBEC (buck converter) sold by Adafruit
// can provide up to 3A continuous, or up to 5A for VERY BRIEF intervals.
// The default CURRENT_MAX setting is a little above the continuous value,
// figuring light painting tends to run for short periods and/or that not
// every scanline will demand equal current.  For extremely long or bright
// images or longer strips, this may exceed the UBEC's capabilities, in
// which case it shuts down (will need to disconnect battery).  If you
// encounter this situation, set CURRENT_MAX to 3000.  Alternately, a more
// powerful UBEC can be substituted (RC hobby shops may have these),
// setting CURRENT_MAX to suit.

// Define ENCODERSTEPS to use rotary encoder rather than timer to advance
// each line.  The encoder MUST be on the T1 pin...this is digital pin 5
// on the Arduino Uno...check datasheet/pinout ref for other board types.
//#define ENCODERSTEPS 8 // # of steps needed to advance 1 line


// NON-CONFIGURABLE STUFF ----------------------------------------------------

#define OVERHEAD 150 // Extra microseconds for loop processing, etc.

uint8_t           sdBuf[512],  // One SD block (also for NeoPixel color data)
pinMask;     // NeoPixel pin bitmask
uint16_t          maxLPS,      // Max playback lines/sec
nFrames = 0, // Total # of image files
          frame   = 0; // Current image # being painted
uint32_t          firstBlock,  // First block # in temp working file
nBlocks;     // Number of blocks in file
Sd2Card           card;        // SD card global instance (only one)
SdVolume          volume;      // Filesystem global instance (only one)
SdFile            root;        // Root directory (only one)
volatile uint8_t *port;        // NeoPixel PORT register
uint16_t brightnessLevel;
uint16_t speedLevel;
// INITIALIZATION ------------------------------------------------------------

void setup() {
    uint8_t  b, startupTrigger, minBrightness;
    char     infile[13], outfile[13];
    boolean  found;
    uint16_t i, n;
    SdFile   tmp;
    uint32_t lastBlock;


    //digitalWrite(TRIGGER, HIGH);           // Enable pullup on trigger button
     // Poll startup trigger ASAP
    pinMode(TRIGGER, INPUT);
    Serial.begin(9600);
    startupTrigger=readTrigger();
    
     
    pinMode(LED_PIN, OUTPUT);              // Enable NeoPixel output
    digitalWrite(LED_PIN, LOW);            // Default logic state = low
    port    = portOutputRegister(digitalPinToPort(LED_PIN));
    pinMask = digitalPinToBitMask(LED_PIN);
    memset(sdBuf, 0, N_LEDS * 3);          // Clear LED buffer
    show();                                // Init LEDs to 'off' stated
#ifdef ENCODERSTEPS
    digitalWrite(5, HIGH);                 // Enable pullup on encoder pin
#endif

    Serial.print(F("Initializing SD card..."));
    if (!card.init(SPI_HALF_SPEED, CARD_SELECT)) {
        error(F("failed. Things to check:\n"
                "* is a card is inserted?\n"
                "* Is your wiring correct?\n"
                "* did you edit CARD_SELECT to match the SD shield or module?"));
    }
    Serial.println(F("OK"));

    if (!volume.init(&card)) {
        error(F("Could not find FAT16/FAT32 partition.\n"
                "Make sure the card is formatted."));
    }
   // Serial.println(F("ABC"));
    root.openRoot(&volume);
     //   Serial.println(F(""));

    // This simple application always reads the files 'frameNNN.bmp' in
    // the root directory; there's no file selection mechanism or UI.

    // If button is held at startup, the processing step is skipped, just
    // goes right to playback of the prior converted file(s) (if present).
    if (startupTrigger == 1) { // No button press
           Serial.println(F("startupTrigger == 1"));
        // Two passes are made over the input images.  First pass counts the
        // files and estimates the max brightness level that the power supply
        // can sustain...
        minBrightness = 255;
        do {
            sprintf(infile, "frame%03d.bmp", nFrames);
            b = 255;
            found = bmpProcess(root, infile, NULL, &b);
            //Serial.print("Found: ");
           // Serial.println(found);
            if (found) { // b modified to safe max
                nFrames++;
                if (b < minBrightness) minBrightness = b;
            }
        } while (found && (nFrames < 1000));
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

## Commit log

2016-08-06 Added Schematics for the Shield
2016-08-06 LED Ring Example
2016-08-30 Updated Schematics
2016-10-27 LED Ring Demo Updated
2016-11-07 Schematics Updated
2016-11-18 Added v2 Gerbers and BOM
    [BOM.xlsx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]
2017-01-02 V1 changes
    [BOM.xlsx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]
2017-01-07 Updated Links
    [BOM.xlsx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]
2018-12-08 Arduino Code for Github With Blynk
